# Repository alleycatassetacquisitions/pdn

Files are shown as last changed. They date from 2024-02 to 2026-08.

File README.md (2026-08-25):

# Portable Data Node (PDN) by Alleycat Asset Acquisitions

Welcome to the official repository for Alleycat Asset Acquisitions' **Portable Data Node (PDN)** project. The PDN is a cutting-edge, interactive device used in live-action role-playing (LARP) environments like [Neotropolis](https://www.neotropolis.com). It leverages real-time technology and augmented reality to create immersive gameplay experiences. The PDN serves as a versatile tool for communication, mission tracking, and player interaction.

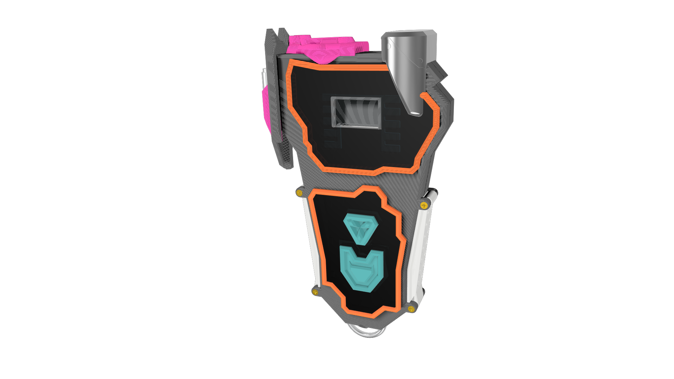
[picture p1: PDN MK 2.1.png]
PDN MK 2.1 Fusion Model (https://a360.co/4ls4MnI)

Clicking on the image will take you to the fusion 360 project!

PCB's were designed in KiCad 8 and will be uploaded to a separate repository soon.

## Table of Contents

- [About the Project](#about-the-project)
- [Project Goals](#project-goals)
- [Features](#features)
- [Installation](#installation)
- [Usage](#usage)
- [Development](#development)
- [Contributing](#contributing)
- [License](#license)
- [Contact](#contact)

## About the Project

The Alleycat Asset Acquisitions Portable Data Node is the premiere device for facilitating immersive experiences and in person, interactive play. You can find Elli Furedy's talk from Hackaday Supercon 2025 on the PDN and Alleycat's philosophies [here](https://youtu.be/ndodsA254HA).

You can find the developer wiki [here](https://deepwiki.com/alleycatassetacquisitions/pdn).

## Project Goals

- **Immersive Icebreaker**: At it's core, the PDN is designed to facilitate face to face experiences.
- **Open Source Collaboration**: Foster collaboration by making the PDN's software and hardware designs available to the community for further improvement. Check out the PDN CLI tool for development tools without needing a physical device.

## Features

- **Extensible Platform**: The PDN currently supports a single experience - the Neotropolis Quickdraw game, however, it is trivial to create new State Machines to support new game experiences.
- **Peripheral Rich**: The base PDN design supports a 128x64 OLED, 19 LEDs, vibration haptics, 2 buttons, ESP-NOW, HTTP and Serial communication.
- **Real-Time Tracking**: The PDN supports connecting to a server to update player data in real time.
- **Modular Design**: The PDN framework works off of a "Driver" framework that allows for customizing the hardware, whether to support new hardware platforms or new peripherals.

## Installation

### Prerequisites

- **PlatformIO Core**: Ensure you have PlatformIO installed as it is used for development and flashing the firmware.
- **pioarduino Platform**: This project uses [pioarduino](https://github.com/pioarduino/platform-espressif32), a community fork of the Espressif32 platform with support for newer ESP-IDF and Arduino framework versions.
- **Unix Style Terminal**: Required for the CLI simulator tool. Windows users should use WSL (Windows Subsystem for Linux).

### Steps

1. Clone the repository:
   ```bash
   git clone https://github.com/AlleycatAssetAcquisitions/pdn
   ```

2. Navigate to the project directory:
   ```bash
   cd pdn/
   ```

3. Install PlatformIO Core:
   ```bash
   pip install platformio
   # or
   platformio upgrade
   ```

4. Configure WiFi credentials (for ESP32-S3 builds):
   ```bash
   cp wifi_credentials.ini.example wifi_credentials.ini
   ```
   Then edit `wifi_credentials.ini` with your WiFi SSID, password, and API base URL. This file is excluded from version control for security.

5. Build the project using PlatformIO:
   ```bash
   pio run -e <build-target>
   ```
   Depending on your use case, there are a number of build targets:
   - `esp32-s3_pdn_release` - Release build (NO LOGS)
   - `esp32-s3_pdn_debug` - Standard Development build
   - `native_cli` - Build the native CLI tool for simulated development (Unix/WSL only)

6. Flash the PDN firmware to your device:
   ```bash
   platformio run --target upload
   ```

### Migration from Standard PlatformIO Espressif32

This project recently migrated from the standard PlatformIO Espressif32 platform to **pioarduino** for access to newer ESP-IDF versions and improved Arduino framework support.

Uninstall PlatformIO from your IDE.
Install pioarduino.
Restart your IDE.

If you're experiencing build issues after pulling recent changes, perform a clean install:

```bash
# Remove old platform packages
rm -rf ~/.platformio/platforms/espressif32*
rm -rf ~/.platformio/packages/framework-arduinoespressif32*

# Clean the project build cache
rm -rf .pio/

# Rebuild
pio run -e esp32-s3_pdn_release
```

## Usage

1. **Power on the PDN**: Once powered, the PDN will ask for your player registration code. This is a 4 digit code that is transmitted to the server to fetch player details. The **top button** cycles through digits, 0 through 9, while the **bottom button** functions as a confirm operation.

2. **Log in to Device**: After entering the code, the device will attempt to fetch data from the server. If there is no server running, it will default to offline mode. You will need to **confirm the player code**, **select a role - Hunter/Bounty** and then confirm. The device will launch into the idle state and you will then be able to practice quickdraw duels with another device.

3. **For Simulated Development**: See CLI_README.md for development without a hardware device.

## Development

### Local Development

If you want to contribute to the PDN Project, follow these steps to set up your local development environment:

1. **Fork the repository** and create your development branch:
   ```bash
   git checkout -b feature/NewFeature
   ```

2. **Develop your feature**
3. **Test on Device/CLI** - CLI tests are sufficient if the hardware layer is unchanged, if any changes are made to drivers our core device logic, features need to be tested on device as well.
3. **Add any new tests** - these should be located in `test/test_core` or `test/test_cli`
4. **Run the test suite** - ensure your changes haven't broken any unit tests.
   ```bash
   pio test -e native          # Core unit tests
   pio test -e native_cli_test # CLI-specific tests
   ```
   CI also gates on the core suite under sanitizers. Run those binaries directly:
   a default `pio test` prints only lines its googletest parser recognizes, so a
   sanitizer report is dropped.
   ```bash
   pio test -e native_asan --without-testing && ./.pio/build/native_asan/program
   pio test -e native_tsan --without-testing && ./.pio/build/native_tsan/program
   ```
5. **Commit and push your changes**:
   ```bash
   git commit -m "Add New Feature"
   git push origin feature/NewFeature
   ```
6. **Create a pull request** for review. Ensure your PR is passing all checks before merging.

### Code Structure

- `include/device/`: This is the hardware abstraction layer that hides all the hardware implementation.
- `include/device/drivers/`: Provides the concrete implementation of hardware peripherals. The native drivers are used for running the CLI tool. 
- `include/game/`: Contains code for game experiences.
- `include/state/`: The core plumbing of the State Machine, the core class that powers games.
- `test/`: Unit testing files for ensuring code stability.
- `platformio.ini`: Project configuration file for PlatformIO, defining build environments and dependencies.

## Contributing

Alleycat wants YOUR HELP! Whether you have feature suggestions, bug reports, or improvements, please follow our [contributing guidelines](CONTRIBUTING.md).

### How to Contribute

1. **Fork the repository**.
2. **Create a new branch** for your feature or bug fix.
3. **Commit your changes** with a descriptive message.
4. **Submit a pull request** for review.

## License

This project is licensed under the MIT License. See the [LICENSE](LICENSE) file for details.

## Contact

For any questions, collaboration opportunities, or technical issues, please reach out to us:

- **Email**: [alleycatassetacquisitions@gmail.com](mailto:alleycatassetacquisitions@gmail.com)
- **Website**: [alleycat.agency](https://alleycat.agency)

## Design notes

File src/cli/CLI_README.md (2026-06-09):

# PDN CLI Simulator

The CLI tool allows you to simulate a network of pdn's to test and build games without having to worry about device deployment and hw related concerns

## Platform Requirements

**Unix/POSIX only** Windows users should use WSL or Git Bash.

The tool requires POSIX terminal APIs (`termios`, `fcntl`) for raw input handling and ANSI escape codes for the UI.

## Building

```bash
pio run -e native_cli
```

## Running

```bash
.pio/build/native_cli/program [num_devices]
```

- `num_devices` (optional): Number of PDN devices to spawn (default: 2)
- Devices alternate roles: Device 0 = Hunter, Device 1 = Bounty, Device 2 = Hunter, etc.
- Device IDs start at `0010` and increment

## Controls

| Key | Action |
|-----|---|
| `←` / `→` | Select previous/next device |
| `↑` | Primary button press (selected device) |
| `↓` | Secondary button press (selected device) |
| `q` | Quit simulator |

## Commands

Type commands at the prompt and press Enter:

| Command | Description |
|---|---|
| `help` | Show all available commands |
| `select <n>` | Select device by index (e.g., `select 1`) |
| `add [hunter\|bounty]` | Add a new device at runtime |
| `cable <a> <b>` | Connect devices via serial cable |
| `disconnect <n>` | Disconnect device's serial cable |
| `press <n> [primary\|secondary]` | Simulate button press |
| `longpress <n> <ms>` | Simulate long press with duration |
| `peer <src> <dst> <type> [hex]` | Send ESP-NOW packet between devices |
| `inject <dst> <type> [hex]` | Inject ESP-NOW packet from external source |
| `state` | Show all device states |
| `http [online\|offline]` | Toggle mock HTTP server state |

## UI Panel

The selected device displays a detailed panel showing:

- **Player Info**: ID, allegiance, win/loss record
- **State**: Current game state with history
- **Display**: Simulated 128x64 OLED content (text mode)
- **LEDs**: Left/Right light strips with RGB values
- **Serial Ports**: Buffer sizes, connection status, TX/RX history
- **ESP-NOW**: Connection state, MAC address, packet history
- **HTTP**: Mock server status, request history
- **Errors**: Recent LOG_E messages

## Serial Cable Simulation

The `cable` command simulates plugging in an audio cable between two devices:

- **Hunter ↔ Bounty**: Connects Primary-to-Primary jacks (normal gameplay)
- **Same role**: Connects Primary-to-Auxiliary jacks

Example workflow:
```
cable 0 1          # Connect hunter (0) to bounty (1)
disconnect 0       # Disconnect device 0's cable
```

## Mock HTTP Server

The simulator includes a mock HTTP server that handles:

- `GET /api/players/{id}` - Returns player data
- `PUT /api/matches` - Accepts match uploads

Use `http offline` to simulate network failures.

## Example Session

```bash
# Start with 2 devices (hunter + bounty)
.pio/build/native_cli/program 2

# In the simulator:
cable 0 1              # Connect devices - starts handshake
# Watch devices progress through: Idle → Handshake → ConnectionSuccessful → DuelCountdown → Duel

# Press buttons during duel
press 0 primary        # Hunter presses button
press 1 primary        # Bounty presses button
```

## Architecture

The CLI simulator reuses the core PDN game logic with native driver implementations:

- `NativeSerialDriver` - Buffered serial with cable broker integration
- `NativePeerCommsDriver` - ESP-NOW simulation via `NativePeerBroker`
- `NativeHttpClientDriver` - Mock HTTP via `MockHttpServer`
- `NativeDisplayDriver` - Text-based display capture
- `NativeLightStripDriver` - LED state tracking
- `NativeButtonDriver` - Callback-based button simulation

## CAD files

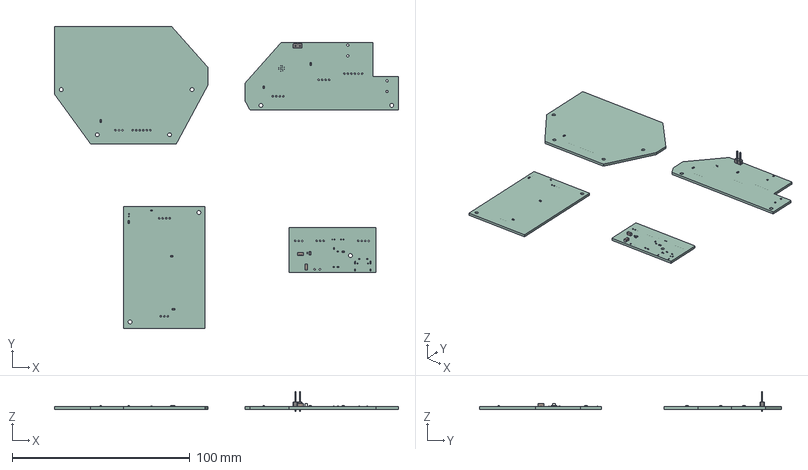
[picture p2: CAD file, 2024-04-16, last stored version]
pdn-pcb/PDN.step
193.7 x 169.8 x 11.5 mm
PCB1
PCB2
PCB3
PCB4

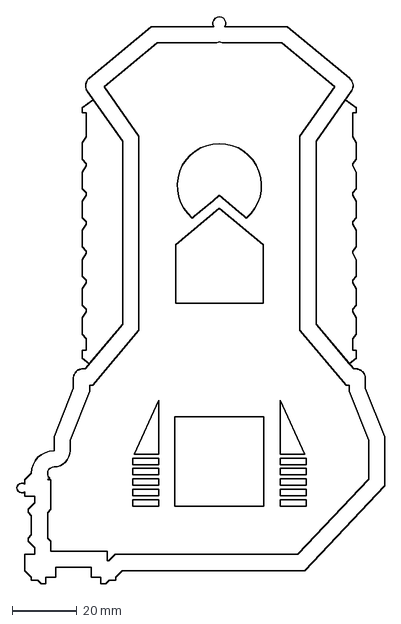
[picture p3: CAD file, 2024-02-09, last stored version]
pdn-pcb/outline.dxf
113.7 x 175.0 mm

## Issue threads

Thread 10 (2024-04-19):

flip the audio jack from "flipped arrangement of ground first" to avoid shorts

FinallyEve, 2024-04-19:

Closed 2024-07-03.

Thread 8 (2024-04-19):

add a rule that if you press during countdown, you lose to avoid holding down button

FinallyEve, 2024-04-19:
reminder

Closed 2024-07-03.

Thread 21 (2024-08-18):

Target Selection Design Doc

FinallyEve, 2024-08-18:
Need to render a list of who is nearby:
- tie a device ping to an identity (currently done, player info bcast in Dan's branch [name, role, id])
- need to display to user the list of nearby (sorted by LIFO order) aka most recent pings
- Some means of cycling through list of nearby users
- Selecting a user will cause that user's PDN to react through lighting up
- Attacking user then confirms selection and initiates targeting.

Possible Powerup Interactions:
- Stealth (doesn't alert user)
- Cloaking - User doesn't show up in other player's pings.

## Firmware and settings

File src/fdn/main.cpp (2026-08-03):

#include <Arduino.h>

#include <WiFi.h>
#include <FastLED.h>
#include <Preferences.h>

#include "device/crash/crash-logger.hpp"
#include "device/drivers/esp32-s3/esp32-s3-logger-driver.hpp"
#include "device/drivers/esp32-s3/esp32-s3-clock-driver.hpp"
#include "device/drivers/esp32-s3/esp32-s3-1-button-driver.hpp"
#include "device/drivers/esp32-s3/ws2812b-fastled-driver.hpp"
#include "device/drivers/esp32-s3/esp32-s3-haptics-driver.hpp"
#include "device/drivers/esp32-s3/esp32-s3-serial-driver.hpp"
#include "device/drivers/esp32-s3/esp32-s3-http-client-driver.hpp"
#include "device/drivers/esp32-s3/esp-now-driver.hpp"
#include "device/drivers/esp32-s3/ssd1309-u8g2-driver.hpp"
#include "device/drivers/esp32-s3/esp32-s3-prefs-driver.hpp"

#include "fdn-constants.hpp"
#include "utils/simple-timer.hpp"
#include "game/player.hpp"
#include "device/fdn.hpp"
#include "wireless/remote-player-manager.hpp"
#include "wireless/fdn-connect-wireless-manager.hpp"
#include "wireless/symbol-wireless-manager.hpp"
#include "wireless/wireless-types.hpp"
#include "device/drivers/peer-comms-interface.hpp"
#include "apps/main-menu/main-menu.hpp"
#include "apps/idle/idle.hpp"
#include "apps/hacking/hacking.hpp"
#include "apps/hacking/hacked-players-manager.hpp"
#include "apps/symbol-match/symbol-match.hpp"
#include "apps/fdn-app-ids.hpp"

// WiFi configuration - injected at compile time from wifi_credentials.ini
// See wifi_credentials.ini.example for template
#ifndef WIFI_SSID
#error "WIFI_SSID not defined. Please create wifi_credentials.ini from wifi_credentials.ini.example"
#endif
#ifndef WIFI_PASSWORD
#error "WIFI_PASSWORD not defined. Please create wifi_credentials.ini from wifi_credentials.ini.example"
#endif
#ifndef BASE_URL
#error "BASE_URL not defined. Please create wifi_credentials.ini from wifi_credentials.ini.example"
#endif

WifiConfig* wifiConfig = nullptr;
CrashLogger* crashLogger = nullptr;
// ESP32-S3 Drivers
Esp32S3Clock*    clockDriver              = nullptr;
SSD1309U8G2Driver* displayDriver         = nullptr;
Esp32S31ButtonDriver* primaryButtonDriver   = nullptr;
Esp32S31ButtonDriver* secondaryButtonDriver = nullptr;
Esp32S31ButtonDriver* tertiaryButtonDriver  = nullptr;
// Recess lights on DISPLAY pin slot, fin lights on GRIP pin slot
WS2812BFastLEDDriver<fdnRecessLightsPin, fdnFinLightsPin>* lightDriver = nullptr;
Esp32S3HapticsDriver* hapticsDriver      = nullptr;
Esp32s3SerialIn* serialInDriver          = nullptr;
Esp32s3SerialInSecondary* serialInSecondaryDriver = nullptr;
Esp32S3HttpClient* httpClientDriver      = nullptr;
EspNowDriver*   peerCommsDriver         = nullptr;
Esp32S3Logger*   loggerDriver            = nullptr;
Esp32S3PrefsDriver* storageDriver        = nullptr;

// FDN device
FDN* fdn = nullptr;

// Player identity
Player fdnPlayer = FDN_PLAYER;

// Managers
RemotePlayerManager*      remotePlayerManager      = nullptr;
FDNConnectWirelessManager* fdnConnectWirelessManager = nullptr;
HackedPlayersManager*     hackedPlayersManager     = nullptr;
SymbolWirelessManager*    symbolWirelessManager    = nullptr;

// Apps
MainMenu*    mainMenu        = nullptr;
Idle*        idleApp         = nullptr;
Hacking*     hackingApp      = nullptr;
SymbolMatch* symbolMatchApp  = nullptr;

static constexpr unsigned long PLAYER_BROADCAST_INTERVAL_MS = 12000;

static void setupEspNow(PeerCommsInterface* peerComms) {
    peerComms->setPacketHandler(
        PktType::kPlayerInfoBroadcast,
        [](const uint8_t* src, const uint8_t* data, size_t len, void* arg) {
            static_cast<RemotePlayerManager*>(arg)->ProcessPlayerInfoPkt(src, data, len);
        },
        remotePlayerManager);

    peerComms->setPacketHandler(
        PktType::kFdnConnect,
        [](const uint8_t* src, const uint8_t* data, size_t len, void* arg) {
            static_cast<FDNConnectWirelessManager*>(arg)->processPacket(src, data, len);
        },
        fdnConnectWirelessManager);

    peerComms->setPacketHandler(
        PktType::kSymbolMatchCommand,
        [](const uint8_t* src, const uint8_t* data, size_t len, void* arg) {
            static_cast<SymbolWirelessManager*>(arg)->processSymbolMatchCommand(src, data, len);
        },
        symbolWirelessManager);
}

void setup() {
    Serial.begin(115200);
    // Do not block on Serial — USB CDC may have no host in the field; setup must run anyway.

    // Construct platform drivers first — logging and timers depend on these.
    loggerDriver = new Esp32S3Logger(LOGGER_DRIVER_NAME);
    clockDriver  = new Esp32S3Clock(PLATFORM_CLOCK_DRIVER_NAME);

    g_logger = loggerDriver;
    SimpleTimer::setPlatformClock(clockDriver);
    esp_log_level_set("*", ESP_LOG_VERBOSE);

    // Remaining drivers (safe to log now)
    displayDriver = new SSD1309U8G2Driver(
        DISPLAY_DRIVER_NAME, fdnDisplayCS, fdnDisplayDC, fdnDisplayRST);
    primaryButtonDriver   = new Esp32S31ButtonDriver(PRIMARY_BUTTON_DRIVER_NAME,   fdnPrimaryButtonPin);
    secondaryButtonDriver = new Esp32S31ButtonDriver(SECONDARY_BUTTON_DRIVER_NAME, fdnSecondaryButtonPin);
    tertiaryButtonDriver  = new Esp32S31ButtonDriver(TERTIARY_BUTTON_DRIVER_NAME,  fdnTertiaryButtonPin);
    lightDriver = new WS2812BFastLEDDriver<fdnRecessLightsPin, fdnFinLightsPin>(
        LIGHT_DRIVER_NAME, fdnNumRecessLights, fdnNumFinLights);
    hapticsDriver = new Esp32S3HapticsDriver(HAPTICS_DRIVER_NAME, fdnMotorPin);
    serialInDriver          = new Esp32s3SerialIn(SERIAL_IN_DRIVER_NAME, fdnRXt, fdnRXr);
    serialInSecondaryDriver = new Esp32s3SerialInSecondary(SERIAL_IN_SECONDARY_DRIVER_NAME, fdnRXt2, fdnRXr2);

    wifiConfig    = new WifiConfig(WIFI_SSID, WIFI_PASSWORD, BASE_URL);
    peerCommsDriver = EspNowDriver::CreateEspNowManager(PEER_COMMS_DRIVER_NAME);
    httpClientDriver = new Esp32S3HttpClient(HTTP_CLIENT_DRIVER_NAME, wifiConfig);
    storageDriver = new Esp32S3PrefsDriver(STORAGE_DRIVER_NAME, {FDN_PREF_NAMESPACE, CRASH_LOG_NAMESPACE});

    DriverConfig fdnConfig = {
        {DISPLAY_DRIVER_NAME,              displayDriver},
        {PRIMARY_BUTTON_DRIVER_NAME,       primaryButtonDriver},
        {SECONDARY_BUTTON_DRIVER_NAME,     secondaryButtonDriver},
        {TERTIARY_BUTTON_DRIVER_NAME,      tertiaryButtonDriver},
        {LIGHT_DRIVER_NAME,                lightDriver},
        {HAPTICS_DRIVER_NAME,              hapticsDriver},
        {SERIAL_IN_DRIVER_NAME,            serialInDriver},
        {SERIAL_IN_SECONDARY_DRIVER_NAME,  serialInSecondaryDriver},
        {HTTP_CLIENT_DRIVER_NAME,          httpClientDriver},
        {PEER_COMMS_DRIVER_NAME,           peerCommsDriver},
        {PLATFORM_CLOCK_DRIVER_NAME,       clockDriver},
        {LOGGER_DRIVER_NAME,               loggerDriver},
        {STORAGE_DRIVER_NAME,              storageDriver},
    };

    fdn = FDN::createFDN(fdnConfig);
    fdn->begin();

    // Managers — constructed after fdn->begin() so wireless is ready.
    remotePlayerManager = new RemotePlayerManager(peerCommsDriver);
    remotePlayerManager->StartBroadcastingPlayerInfo(&fdnPlayer, PLAYER_BROADCAST_INTERVAL_MS);

    fdnConnectWirelessManager = new FDNConnectWirelessManager();
    fdnConnectWirelessManager->initialize(fdn->getWirelessManager());

    hackedPlayersManager  = new HackedPlayersManager(fdn->getStorage());

    symbolWirelessManager = new SymbolWirelessManager();
    symbolWirelessManager->initialize(fdn->getWirelessManager(), fdn->getRemoteDeviceCoordinator());

    setupEspNow(peerCommsDriver);

    crashLogger = new CrashLogger(storageDriver, peerCommsDriver);
    crashLogger->capture();
    crashLogger->transmitPending();

    // Apps
    idleApp = new Idle(
        remotePlayerManager, hackedPlayersManager,
        fdnConnectWirelessManager, fdn->getRemoteDeviceCoordinator());

    mainMenu = new MainMenu(fdn, remotePlayerManager);

    hackingApp = new Hacking(
        fdnConnectWirelessManager, hackedPlayersManager,
        fdn->getRemoteDeviceCoordinator());

    symbolMatchApp = new SymbolMatch(
        fdn, symbolWirelessManager,
        remotePlayerManager, hackedPlayersManager,
        fdnConnectWirelessManager);

    // Splash screen
    fdn->getDisplay()
        ->invalidateScreen()
        ->drawText("ALLEYCAT", 20, 32)
        ->render();
    delay(2000);

    AppConfig apps = {
        {StateId(SYMBOL_MATCH_APP_ID), symbolMatchApp},
        {StateId(MAIN_MENU_APP_ID),    mainMenu},
        {StateId(HACKING_APP_ID),      hackingApp},
        {StateId(IDLE_APP_ID),         idleApp},
    };
    fdn->loadAppConfig(apps, StateId(SYMBOL_MATCH_APP_ID));
}

void loop() {
    if (crashLogger != nullptr) {
        crashLogger->pollSerialCommand();
    }
    fdn->loop();
}

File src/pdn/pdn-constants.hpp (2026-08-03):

#pragma once

#include <cstdint>

// --- GPIO pin assignments ---
constexpr uint8_t primaryButtonPin   = 15;
constexpr uint8_t secondaryButtonPin = 16;
constexpr uint8_t motorPin           = 17;
constexpr uint8_t RXr                = 41;
constexpr uint8_t RXt                = 40;
constexpr uint8_t TXt                = 39; // MIDDLE BAND ON AUDIO CABLE
constexpr uint8_t TXr                = 38; // TIP OF AUDIO CABLE
constexpr uint8_t displayLightsPin   = 13;
constexpr uint8_t gripLightsPin      = 21;
constexpr uint8_t displayCS          = 10;
constexpr uint8_t displayDC          = 9;
constexpr uint8_t displayRST         = 14;

// --- LED strip lengths ---
constexpr uint8_t numDisplayLights = 13;
constexpr uint8_t numGripLights    = 6;

// --- Game timing ---
constexpr unsigned long DUEL_NO_RESULT_TIME = 123456789;

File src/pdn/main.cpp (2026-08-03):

#include <Arduino.h>

#include <WiFi.h>
#include <FastLED.h>
#include <Preferences.h>

#include "device/drivers/esp32-s3/esp32-s3-logger-driver.hpp"
#include "device/drivers/esp32-s3/esp32-s3-clock-driver.hpp"
#include "device/drivers/esp32-s3/esp32-s3-1-button-driver.hpp"
#include "device/drivers/esp32-s3/ws2812b-fastled-driver.hpp"
#include "device/drivers/esp32-s3/esp32-s3-haptics-driver.hpp"
#include "device/drivers/esp32-s3/esp32-s3-serial-driver.hpp"
#include "device/drivers/esp32-s3/esp32-s3-http-client-driver.hpp"
#include "device/drivers/esp32-s3/esp-now-driver.hpp"
#include "device/drivers/esp32-s3/ssd1306-u8g2-driver.hpp"
#include "device/drivers/esp32-s3/esp32-s3-prefs-driver.hpp"
#include "device/crash/crash-logger.hpp"

#include "pdn-constants.hpp"
#include "utils/simple-timer.hpp"
#include "game/player.hpp"
#include "state/state-machine.hpp"
#include "device/pdn.hpp"
#include "game/quickdraw.hpp"
#include "id-generator.hpp"
#include "wireless/remote-player-manager.hpp"
#include "game/match-manager.hpp"
#include "wireless/wireless-types.hpp"
#include "wireless/quickdraw-wireless-manager.hpp"
#include "wireless/remote-debug-manager.hpp"
#include "wireless/symbol-wireless-manager.hpp"
#include "device/drivers/peer-comms-interface.hpp"
#include "game/quickdraw-resources.hpp"

// WiFi configuration - injected at compile time from wifi_credentials.ini
// See wifi_credentials.ini.example for template
#ifndef WIFI_SSID
#error "WIFI_SSID not defined. Please create wifi_credentials.ini from wifi_credentials.ini.example"
#endif
#ifndef WIFI_PASSWORD
#error "WIFI_PASSWORD not defined. Please create wifi_credentials.ini from wifi_credentials.ini.example"
#endif
#ifndef BASE_URL
#error "BASE_URL not defined. Please create wifi_credentials.ini from wifi_credentials.ini.example"
#endif

WifiConfig* wifiConfig = nullptr;

CrashLogger* crashLogger = nullptr;


// ESP32-s3 Drivers (declare as pointers, construct in setup())
Esp32S3Clock* clockDriver = nullptr;
SSD1306U8G2Driver* displayDriver = nullptr;
Esp32S31ButtonDriver* primaryButtonDriver = nullptr;
Esp32S31ButtonDriver* secondaryButtonDriver = nullptr;
WS2812BFastLEDDriver<displayLightsPin, gripLightsPin>* lightDriver = nullptr;
Esp32S3HapticsDriver* hapticsDriver = nullptr;
Esp32s3SerialOut* serialOutDriver = nullptr;
Esp32s3SerialIn* serialInDriver = nullptr;
Esp32S3HttpClient* httpClientDriver = nullptr;
EspNowDriver* peerCommsDriver = nullptr;
Esp32S3Logger* loggerDriver = nullptr;
Esp32S3PrefsDriver* storageDriver = nullptr;

// Core game objects (declare as pointers, construct in setup())
Device* pdn = nullptr;
Player* player = nullptr;

// Game instance
Quickdraw* game = nullptr;

// Remote player management
QuickdrawWirelessManager* quickdrawWirelessManager = nullptr;
SymbolWirelessManager* symbolWirelessManager = nullptr;
RemoteDebugManager* remoteDebugManager = nullptr;

void setupEspNow(
    QuickdrawWirelessManager* quickdrawWirelessManager,
    RemoteDebugManager* remoteDebugManager,
    SymbolWirelessManager* symbolWirelessManager,
    PeerCommsInterface* peerCommsDriver) {
    // Register packet handlers
    peerCommsDriver->setPacketHandler(
        PktType::kQuickdrawCommand,
        [](const uint8_t* src, const uint8_t* data, const size_t len, void* userArg) {
            ((QuickdrawWirelessManager*)userArg)->processQuickdrawCommand(src, data, len);
        },
        quickdrawWirelessManager
    );
    
    peerCommsDriver->setPacketHandler(
        PktType::kDebugPacket,
        [](const uint8_t* srcAddr, const uint8_t* data, const size_t len, void* userArg) {
            ((RemoteDebugManager*)userArg)->ProcessDebugPacket(srcAddr, data, len);
        },
        remoteDebugManager
    );

    peerCommsDriver->setPacketHandler(
        PktType::kSymbolMatchCommand,
        [](const uint8_t* srcAddr, const uint8_t* data, const size_t len, void* userArg) {
            ((SymbolWirelessManager*)userArg)->processSymbolMatchCommand(srcAddr, data, len);
        },
        symbolWirelessManager
    );
}

void setup() {
    Serial.begin(115200);
    // Do not block on Serial — USB CDC may have no host in the field; setup must run anyway.

    // Construct drivers FIRST (before anything that might use logging or timers)
    loggerDriver = new Esp32S3Logger(LOGGER_DRIVER_NAME);
    clockDriver = new Esp32S3Clock(PLATFORM_CLOCK_DRIVER_NAME);
    
    // Initialize platform abstractions immediately after constructing them
    g_logger = loggerDriver;
    SimpleTimer::setPlatformClock(clockDriver);
    esp_log_level_set("*", ESP_LOG_VERBOSE);

    // Now construct remaining drivers (safe to use logging and timers now)
    displayDriver = new SSD1306U8G2Driver(DISPLAY_DRIVER_NAME, displayCS, displayDC, displayRST);
    primaryButtonDriver = new Esp32S31ButtonDriver(PRIMARY_BUTTON_DRIVER_NAME, primaryButtonPin);
    secondaryButtonDriver = new Esp32S31ButtonDriver(SECONDARY_BUTTON_DRIVER_NAME, secondaryButtonPin);
    lightDriver = new WS2812BFastLEDDriver<displayLightsPin, gripLightsPin>(LIGHT_DRIVER_NAME, numDisplayLights, numGripLights);
    hapticsDriver = new Esp32S3HapticsDriver(HAPTICS_DRIVER_NAME, motorPin);
    serialOutDriver = new Esp32s3SerialOut(SERIAL_OUT_DRIVER_NAME, TXt, TXr);
    serialInDriver = new Esp32s3SerialIn(SERIAL_IN_DRIVER_NAME, RXt, RXr);
    
    // WiFi credentials are compile-time constants from build flags
    wifiConfig = new WifiConfig(WIFI_SSID, WIFI_PASSWORD, BASE_URL);
    peerCommsDriver = EspNowDriver::CreateEspNowManager(PEER_COMMS_DRIVER_NAME);
    httpClientDriver = new Esp32S3HttpClient(HTTP_CLIENT_DRIVER_NAME, wifiConfig);
    storageDriver = new Esp32S3PrefsDriver(STORAGE_DRIVER_NAME, {MATCHES_PREFS_NAMESPACE, CRASH_LOG_NAMESPACE});

    // Create driver configuration
    DriverConfig pdnConfig = {
        {DISPLAY_DRIVER_NAME, displayDriver},
        {PRIMARY_BUTTON_DRIVER_NAME, primaryButtonDriver},
        {SECONDARY_BUTTON_DRIVER_NAME, secondaryButtonDriver},
        {LIGHT_DRIVER_NAME, lightDriver},
        {HAPTICS_DRIVER_NAME, hapticsDriver},
        {SERIAL_OUT_DRIVER_NAME, serialOutDriver},
        {SERIAL_IN_DRIVER_NAME, serialInDriver},
        {HTTP_CLIENT_DRIVER_NAME, httpClientDriver},
        {PEER_COMMS_DRIVER_NAME, peerCommsDriver},
        {PLATFORM_CLOCK_DRIVER_NAME, clockDriver},
        {LOGGER_DRIVER_NAME, loggerDriver},
        {STORAGE_DRIVER_NAME, storageDriver},
    };
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

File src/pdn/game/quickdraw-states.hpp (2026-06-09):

#pragma once

#include "device/pdn.hpp"
#include "game/player.hpp"
#include "utils/simple-timer.hpp"
#include "utils/debounced-condition.hpp"
#include "state/state.hpp"
#include "state/connect-state.hpp"
#include "wireless/quickdraw-wireless-manager.hpp"
#include "wireless/symbol-wireless-manager.hpp"
#include "wireless/remote-debug-manager.hpp"
#include "game/match-manager.hpp"
#include "device/drivers/http-client-interface.hpp"
#include "game/quickdraw-resources.hpp"
#include <array>
#include <atomic>
#include <cstddef>
#include <cstdlib>
#include <queue>
#include <string>
#include "device/remote-device-coordinator.hpp"
#include "game/chain-duel-manager.hpp"
#include "game/shootout-manager.hpp"

enum QuickdrawStateId {
    SLEEP = 6,
    AWAKEN_SEQUENCE = 7,
    IDLE = 8,
    DUEL_COUNTDOWN = 13,
    DUEL = 14,
    DUEL_PUSHED = 15,
    DUEL_RECEIVED_RESULT = 16,
    DUEL_RESULT = 17,
    WIN = 18,
    LOSE = 19,
    UPLOAD_MATCHES = 20,
    SUPPORTER_READY = 21,
    SHOOTOUT_PROPOSAL = 22,
    SHOOTOUT_BRACKET_REVEAL = 23,
    SHOOTOUT_SPECTATOR = 24,
    SHOOTOUT_ELIMINATED = 25,
    SHOOTOUT_FINAL_STANDINGS = 26,
    SHOOTOUT_ABORTED = 27,
    // Symbol-match IDs sit after the shootout block so neither protocol's
    // wire-visible state IDs collide. Main introduced SYMBOL=22/SYMBOL_MATCHED=23
    // in parallel with shootout taking 22-27; they were renumbered here on merge.
    SYMBOL = 28,
    SYMBOL_MATCHED = 29,
};

class Sleep : public TypedState<PDN> {
public:
    explicit Sleep(Player* player);
    ~Sleep();

    void onStateMounted(PDN* pdn) override;
    void onStateLoop(PDN* pdn) override;
    void onStateDismounted(PDN* pdn) override;
    bool transitionToAwakenSequence();

private:
    bool transitionToAwakenSequenceState = false;
    SimpleTimer dormantTimer;
    Player* player;
    bool breatheUp = true;
    int ledBrightness = 0;
    float pwm_val = 0.0;
    static constexpr int smoothingPoints = 255;
    static constexpr unsigned long SLEEP_DURATION = 60000UL;
};

class AwakenSequence : public TypedState<PDN> {
public:
    explicit AwakenSequence(Player* player);
    ~AwakenSequence();
    void onStateMounted(PDN* pdn) override;
    void onStateLoop(PDN* pdn) override;
    void onStateDismounted(PDN* pdn) override;
    bool transitionToIdle();

private:
    static constexpr int AWAKEN_THRESHOLD = 20;
    SimpleTimer activationSequenceTimer;
    int activateMotorCount = 0;
    bool activateMotor = false;
    const int activationStepDuration = 100;
    Player* player;
};

class Idle : public ConnectState<PDN> {
public:
    Idle(Player *player, MatchManager* matchManager, RemoteDeviceCoordinator* remoteDeviceCoordinator, ChainDuelManager* chainDuelManager);
    ~Idle();

    void onStateMounted(PDN* pdn) override;
    void onStateLoop(PDN* pdn) override;
    void onStateDismounted(PDN* pdn) override;
    bool transitionToDuelCountdown();
    bool transitionToSupporterReady();
    void renderStats(PDN* pdn);
    bool transitionToSymbol();

private:
    Player *player;
    MatchManager* matchManager;
    ChainDuelManager* chainDuelManager;
    bool matchInitialized = false;
    bool displayIsDirty = false;
    int statsIndex = 0;
    int statsCount = 7;
    size_t lastPosseCount = 0;

    bool isPrimaryRequired() override;
    bool isAuxRequired() override;

    SimpleTimer matchInitializationTimer;
    const int MATCH_INITIALIZATION_TIMEOUT = 1000;

    bool transitionToSymbolState = false;

    // void serialEventCallbacks(const std::string& message);
};

class SupporterReady : public ConnectState<PDN> {
public:
    SupporterReady(Player *player, RemoteDeviceCoordinator* remoteDeviceCoordinator, ChainDuelManager* chainDuelManager);
    ~SupporterReady();

    void onStateMounted(PDN* pdn) override;
    void onStateLoop(PDN* pdn) override;
    void onStateDismounted(PDN* pdn) override;
    bool transitionToIdle();

    // Called by Quickdraw's chain-game-event packet handler.
    void onChainGameEventReceived(uint8_t event_type, const uint8_t* senderMac);

public:
    // Button callback in onStateMounted uses these via `this` capture.
    // Atomic because the ESP-NOW packet callback (WiFi task on hardware) and
    // the button press / state-loop callbacks (main task) read and write them
    // concurrently.
    Player *player;
    std::atomic<bool> buttonArmed{false};
    std::atomic<bool> hasConfirmed{false};
    std::atomic<bool> displayIsDirty{true};
    std::atomic<bool> ledsAreDirty{true};
    std::atomic<int> lastResult{0};
    // resultClearTimer is touched only by onStateLoop (main task). The
    // packet handler (WiFi task) communicates via the atomic lastResult;
    // onStateLoop detects transitions and manages the timer here.
    SimpleTimer resultClearTimer;
    PDN* cachedPDN = nullptr;

    void startLEDs(PDN* pdn, bool armed, bool confirmed);

private:
    ChainDuelManager* chainDuelManager;
    bool transitionToIdleFlag = false;
    int lastProcessedResult_ = 0;  // main-task-only; mirrors lastResult

    bool isPrimaryRequired() override;
    bool isAuxRequired() override;
};



class DuelCountdown : public ConnectState<PDN> {
public:
    DuelCountdown(Player* player, MatchManager* matchManager, RemoteDeviceCoordinator* remoteDeviceCoordinator, ChainDuelManager* chainDuelManager);
    ~DuelCountdown();

    void onStateMounted(PDN* pdn) override;
    void onStateLoop(PDN* pdn) override;
    void onStateDismounted(PDN* pdn) override;
    bool shallWeBattle();
    bool disconnectedBackToIdle();

    bool isPrimaryRequired() override;
    bool isAuxRequired() override;
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

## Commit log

2023-10-22 Initial Commit of KiCad Project.
    [PDN.kicad_pcb, PDN.kicad_sch]
2023-10-25 More Parts from JLCPCB
    [PDN.kicad_sch]
2024-02-09 V1 PCB Dev Boards.
    [PDN.kicad_pcb, PDN.kicad_sch, PDN.step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]
2024-03-04 Updated 3v3 LDO to an LDL1117, reworked the brain board and added TVS protection.
    [PDN.kicad_pcb, PDN.kicad_sch, PDN.step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]
2024-03-04 Updated display, user board and display board.
    [PDN.kicad_pcb, brain.kicad_sch, display.kicad_sch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]
2024-03-15 Connected D1 & D2 of Display.
    [PDN.kicad_pcb]
2024-03-15 Fix DRC violations, update side leds.
    [PDN.kicad_pcb]
2024-03-16 Update Brain Board.
    [PDN.kicad_pcb, brain.kicad_sch]
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2024-03-18 Working Debug Menu.
    [PDN.kicad_pcb, power.kicad_sch]
2024-04-16 most recent version pcb and code.
    [PDN.kicad_pcb, PDN.kicad_sch, PDN.step]
2024-04-16 update userID's eeprom usage to avoid losing sense of state
    [main.cpp]
2024-04-16 Switch back to hunter code, clean up serial code.
2024-04-19 added a timeout to checkin and swapped serial order
    [main.cpp]
2024-04-20 bugfixes and debug strings
    [main.cpp]
2024-04-20 find the comms bug
    [main.cpp]
2024-04-20 Remove extra win case from merge with main.
2024-04-21 Swap tx to middle band of trs jack.
    [main.cpp]
2024-04-21 Progress on lights, fixed a bug in bounty activation.
    [main.cpp]
2024-04-22 Corrected match json output.
    [main.cpp]
2024-04-23 Fix enum values for allegiances.
    [main.cpp]
2024-04-23 Move ui refresh to the end of loop, to prevent UI from updating before game state transition.
    [main.cpp]
2024-05-25 Removed PCB from project. All changes from work in the desert on code.
    [PDN.kicad_pcb, PDN.kicad_sch, PDN.step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]
2024-05-31 Change Handshake state to enum
    Switching to enum applies type safety to handshake states to ensure no
    accidental assignments.
2024-05-31 Switch whitespace check to libc
    Use the standard libc isspace instead of custom isWhitespace. This adds
    formfeed ('\f') and vertical tab ('\v') to check which may not be
    desireable, but if it doesn't matter, than this simplifies the code and
    reduces final memory usage by a small amount.
    [main.cpp]
2024-05-31 Begin breaking out comms
    Breaking out communications to separate files reduces the complexity of
    main.cpp, making it easier to read and manage. Eventually, this will
    also allow for more easily swapping between different low level
    communication protocols, such as ESP-NOW or BLE, though more separation
    will be needed first.
    [main.cpp]
2024-06-19 Encapsulate simple timer code
    While the project has the more complex, task based arduino-timer
    library, we often just need a very simple check of duration. main.cpp
    already had a collection of global variables and functions to handle
    this use case. This commit moves those into a simple class to protect
    the variables and also allow for easily having multiple simple timers
    in the future.
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2024-10-09 Device Encapsulation & State Machine (#23)
    * Eve & Elli chaos.
    * Improving device class.
    * I guess I should commit this mess just in case.
    * Flesh out State Machine further.
    * more state machine work.
    * Add StateWithStateMachine to allow for ssub-state-machine processes.
    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
2024-10-09 Unit Testing! (#27)
    * Working tests with mocked device class.
    * Added more State machine Tests
    * Added several more tests.
    * Added state tests.
    * Move project out of pdn-code directory and add test-runner.
    * Add test runner.
2024-10-15 add step to build esp32-s3 image on pr. (#29)
    * add step to build esp32-s3 image on pr.
    * remove source filter from esp32 env.
2024-10-16 Device API's (#30)
    * Add display api to device.
    * refactoring haptics, button and display.
    * wip
    * a lot of device stuff.
2024-11-18 Bug fixes all over the place. (#34)
    [main.cpp, quickdraw-states.hpp]
2024-11-25 Core Game Loop Working on new Architecture. (#35)
    * Fix Player match and opponent id strings being initialized incorrectly.
    * Working Quickdraw duels.
    [quickdraw-states.hpp]
2024-12-20 Add basic P2P wireless capabilities and a remote player discovery (#36)
    * Copy files from initial-esp-now branch
    * Finish esp integration with newer main branch
    This branch replaces the old initial-esp-now branch and this commit
    completes what should be the last of the needed integration. This builds
    but is not at all tested yet.
    * Switch over to using ESP_LOG for logging
    This does not require CDC on boot and also adds extra file information
    to messages, plus adds tagging and log levels, so is all around a
    better solution. You can now see remote player discovery messages
    when using Upload and Monitor command in VSCode.
    ---------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
    [main.cpp]
2025-02-26 Server fuckery (#37)
    * Add MatchManager and refactor match class.
    * Match manager correctly serializes and deserializes match arrays.
    * Fix UUID length issues.
    * clean up warns and main.cpp
    * Add wifi client to device.
    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
    [main.cpp]
2025-03-03 LED Animation Framework - Includes IAnimation Interface & LightManager classes. (#39)
    * fucking with lights
    * lighting algorithms
    * encapsulated light manager
    * create animation interface.
    * Add countdown animation.
    * Add animations.
    * fucking with lights.
    * Working Animation Library with Idle Animation
    * chase led variations.
    * Update hunter idle animation.
    * fix tests.
    [quickdraw-resources.hpp, quickdraw-states.hpp]
2025-03-03 Bounty Idle Animation and more work on animation framework. (#40)
    * New cool idle animation
    * make bounty idle colors better.
    * Separate bounty idle into it's own animation.
    * Added Hunter idle state.
    * Final touches.
2025-03-19 Working wireless (#42)
    * Observer-serial pattern.
    * stuff
    * Handshake over Wireless, debugging serial mac sending.
    * Handshake over Wireless, debugging serial mac sending.
    * Fixed serial, wrote wireless handshake.
    * Bug in bounty handshake
    * Get rid of empty initial file.
    * in the middle of handshake refactor.
    * refactoring handshake
    * fix compile errors.
    * Fix test and compilation errors.
    [main.cpp, quickdraw-states.hpp]
2025-04-04 User Registration Flow w/ Offline Config. (#44)
    * Add loading state!
    * Fetching Player from server
    * True async network calls
    * User Registration Flow with offline config.
2025-04-12 Duel Time (#47)
    * Progress on duel.
    * Duel logic complete but untested.
    * duels working correctly.
    * Moved preferences initialization to later in the event stack. The match manager's constructor was trying to open prefs before the underlying arduino architecture had completed setup.
    * Working match upload after duels, with force match upload function.
    * Add loading ui to upload match state.
    * Clean up some bugs in duel.
    [main.cpp, quickdraw-states.hpp]
2025-04-16 Final 2025 Polish - Lighting Animations, updated draw image, and button masher penalty (#48)
    * Implemented Countdown animation in countdown state.
    * add new lighting states, implemented button masher penalty and prevent repeated play.
    * Further touches.
    [quickdraw-resources.hpp, quickdraw-states.hpp]
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2025-11-01 Build env cleanup (#50)
    * Initial platformio.ini cleanup
    Add a common environment that is shared among all other environments and
    create 3 separate embedded environments:
    1) A release environment that builds with optimizations on and
    minimizes UART serial logging[pdn_release]
    2) A release environment that builds with optimizations on
    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
2026-01-30 Arduino Type Extraction | Driver Framework | Unit Testing
    * Project Clean-Up and Type Extraction
    - cleaned up Readme.md
    - Replaced all instances of arduino String with std::string
    - Addressed ArduinoJson Warnings
    - updated a number of ints to uint_8t.
    - refactored lighting driver.
    * Extract Arduino headers from UUID generator.
    * Refactor SimpleTimer to use a PlatformClock.
    * Created PeerCommsInterface and implemented in ESP-Now-Comms.
    * Created PeerCommsInterface and implemented in ESP-Now-Comms.
    * Refactor Wireless Management, removed wireless manager and created http-client-interface.
    * Fix NPE in simple-timer and move to header implementation.
    * Created logging interface to hide es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
    [main.cpp]
2026-02-02 Driver Update Bug Fixes (#61)
    * progress fixing esp-now/http switching.
    * Fixed wireless state management to restore switching between esp-now and wifi on the esp32.
    * Update logger to output better logs.
    [main.cpp, quickdraw-states.hpp]
2026-02-03 Sonar qube fixes (#60)
    * Sonarqube MCP server setup and fixes.
    * More sonasonar qube fixes
    * Sonar qube analysis issues.
    * Fix compilation errors.
    * Fix test errors after rebase.
    * more fixes.
    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
2026-02-06 PDN CLI Tool (#62)
    * V1 of cli tool.
    * Create multi-device simulator, add http client and add commands.
    * Fix serial driver clearing data before the serial broker could transfer between devices.
    * CLI tool simulates full duels.
    * Add Readme for CLI.
    * Update tests, add test for cli build target.
    [cli-renderer.hpp]
2026-02-06 Move Wifi Credentials to ini file. (#64)
    * Add ini file for wifi configuration.
    * Update character escaping in platformio.ini file
    * Fix github actions to support new wifi-credentials.ini workflow
    [main.cpp]
2026-02-09 Add display mirror with braille rendering, captions, and display commands (#67)
    Overhaul the CLI simulator's display system:
    Driver layer:
    - Proper XBM bitmap decoding via decodeXBMToBuffer (mirrors U8g2)
    - Text glyph backgrounds cleared for visibility over images
    - New renderToBraille() method using Unicode braille (U+2800-U+28FF)
    for 4x detail vs half-blocks, same 64x16 terminal footprint
    Renderer:
    - Terminal height bounds checking prevents scroll corruption
    - Display mirror toggle with braille art rendering
    - Hybrid layout: captions shown alongside first 4 mirror lines
    - Captions toggle (default ON) gates caption visibility
    Commands (moved into CommandProcessor with Renderer& paramet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
    [cli-renderer.hpp]
2026-02-09 Pin the arduinojson version and remove unnecessary build target. (#71)
2026-02-12 Implement state machine management to allow for multiple game experiences (#81)
    * Implement state machine management to allow for multiple game experiences.
    * Fix bugs and add tests.
    * Fix missing serial flush, log statements.
    [main.cpp]
2026-02-15 Break out player registration and handshake from quickdraw. (#90)
    * Break out player registration and handshake from quickdraw.
    * Fix cli tests.
    [main.cpp, quickdraw-resources.hpp, quickdraw-states.hpp]
2026-02-18 Serial Module Implementation (#94)
    * add workspace files to .gitignore
    * SerialManager class implementation
    * add tests to mock device
    * tests
    * routing through SerialManager
    * repairing tests
    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
2026-03-07 Remote Device Coordinator - Enhanced Device Connectivity API for interacting with other devices. (#98)
    * Create RemoteDeviceCoordinator and refactor concepts of handshake.
    Flesh out the RemoteDeviceCoordinator header file.
    Implement RemoteDeviceCoordinator in Quickdraw.
    New Handshakes for RemoteDeviceCoordinator.
    Restructured how handshakes work.
    Add comments to remotedeviceoordinator header.
    * Update to use uint8_t for mac in remote device coordinator.
    * RemoteDeviceCoordinator code for returning one peer
    * build error for HandshakeApp
    * handle null handshake apps
    * cpp17 compatible functions
    * todo stragglers
    * duel state transition to idle fix
    * added serial port ide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
    [main.cpp]
2026-03-27 Update RDC to support multiple device types. (#103)
2026-04-19 RDC chain duel with posse display and loop detection (#110)
    * Chain-duel: daisy-chain topology with supporter boost
    Extends the two-device duel to N-device chains where downstream same-role
    devices act as "supporters" for the champion at the chain head. Supporters
    press their button during COUNTDOWN to send a confirm; each confirm grants
    the champion a 15ms boost on their reaction window.
    ## Transport
    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
2026-04-22 Create a thread safe drain queue for processing incoming ESP-NOW packets. (#112)
    * Create a thread safe drain queue for processing incoming esp-now packets.
    * Update native cli tests.
    * Add similar locks around the send queue.
2026-04-23 Symbol match code for PDN (#114)
    * symbol generation and stats page
    * simple state machine: selection and timer
    * refactoring + introduction of symbol class
    * symbol match connection states
    * symbol manager implementation and connection states
    * symbol match selection flow mostly complete
    * five symbols
    * import errors
    * symbol generation and stats page
    * refactoring + introduction of symbol class
    * symbol manager implementation and connection states
    Made-with: Cursor
    * symbol match selection flow mostly complete
    * pdn symbol match state machine enhancements
    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
    [main.cpp, quickdraw-resources.hpp, quickdraw-states.hpp]
2026-04-24 Shootout tournament mode with RDC loop coordination (#113)
    * Shootout tournament mode with RDC loop coordination
    * Harden shootout: packet validation, disconnect wiring, debounce
    * Shootout hardening + merge upstream main
    * Idle: skip chain-duel init while a shootout is active
    Idle::onStateLoop was calling matchManager->initializeMatch() (chain-duel
    path) while a shootout was underway, overwriting the SHT- match state on
    a bounty device mid-match-1 and stalling the tournament.
    * Shootout: restore original isHunter at each match boundary
    originalIsHunter_ was only restored inside resetToIdle, which doesn't fire
    until a terminal state dismounts (FinalStandings/Aborted). If the ring
    staye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
    [quickdraw-states.hpp]
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2026-06-09 Architecture Migration for Multi-Device Repository (#121)
    * Refactor to prepare for multi-device mono-repo.
    * Create core libraries and separate pdn specific code from core libs.
    * Renormalize line endings to prevent my windows sins to bother everyone else.
    * Remove random readme from include directory.
    * Restore animations. Create utils/easing_curves to remove dependency on quickdraw-resources.
    * Codebase ready for FDN integration.
    * Some small compile issues.
    * Migrate cli code.
    * Convert quickdraw and player registration to TypedStateMachine.
    * Convert ConnectState to always be a device-typed state.
    * Remove AnimationConfig::type and associated cruft code.
    * Remove snapshot cru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
    [cli-renderer.hpp]
2026-06-15 FDN Monorepo Migration (#142)
    * cursor fdn migration
    * restart symnol match game when transitioning back
    * comment unnecessary code
    * broken tests
    [display-utils.hpp, fdn-constants.hpp]
2026-08-03 Crash Log Reporting - With some extras on the side (#221)
    * Add crashlogging with reporting over serial, esp-now or http.
    * Remove forced abort.
    * Allow csv's to be committed so that partitions.csv is part of the codebase.
    * Update json key names for crash logs
    * Add commit hash to commit logs.
    * Remove forced abort again, set up storage driver to throw an exception if invalid namespace is used.
    [partitions.csv]
2026-08-25 Match asan (#260)
    * bound id copies by source; unblock sanitizer suites
    * collapse copyId onto strncpy; guard the setter path
    * surface sanitizer reports in CI; restore capacity guard
    * bound copies by destination; correct sanitizer run notes
    * bound generated match id copy by destination
    * default Match(); document sanitizer gates in README
    * correct sanitizer notes; drop redundant match id copy
    * bound deserialize by destination; revive uuid tests
2026-10-04 Style tooling (#282)
    * Track style config and pre-commit hook
    * Harden style checker against git config and nesting
    * Collapse the no-translation-unit notice to one line
2026-10-14 Idf (#284)
    * build: configure one env on the component path
    (cherry picked from commit dc9d71066ddcc95adebe9b7d6367260401dfb6e2)
    * build: select sources and includes under cmake
    (cherry picked from commit 98c080317285737ea361db586efadb613174624c)
    * drivers: clock, haptics and prefs off arduino
    (cherry picked from commit c5b0d4c535268c0a196d9f52cf637d814acf4d64)
    * drivers: serial jacks on the idf uart driver
    (cherry picked from commit 564ac2bb1c1eb8eaa483aa380abcba5c001dbad9)
    * style: doxygen blocks on the serial driver
    * drivers: esp-now radio and crash log off arduino
    (cherry picked from commit 26714186fb2bd6e965c7bf6c8f5d0390cb678ea8)
    * drivers: wifi station and http off arduino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
2026-10-15 Replace PioArduino w/ Platformio/espressif32 Framework (#289)
    * Collapse State's untyped lifecycle into TypedState<Device>
    * Fix defects IDF's -Wall -Werror reports
    * Build on official espressif32 6.13.0
    * flash_multi: use spellings esptool 4 and 5 accept
    * Make State's lifecycle bridge pure and private again
    * multi_flash: run the platform's esptool.py, not an import
    * Size boostLine for any %lu; correct three comments
    * Correct the StateLifecycle comment on abstract State
    * CI: also build the FDN release and PDN debug envs
    * Updated readme guidance on ide extensions.
    * CI: drop the comment the platform change falsified
2026-10-15 Https Driver adapted for IDF (#291)
    * Verify server certificates and pump async HTTPS transfers
    * HttpRequest carries its own content type
    * One outcome per HTTP attempt, decided from perform()
    * HTTP errors are final: drop willRetry, end attempts cut by disconnect
    * Disconnect fails every queued HTTP request, not just in-flight
    * Native HTTP driver drains its queue on disconnect too
    ---------
2026-10-16 Alleycat-Server & Protobuf Implementation for Device Crash Logs to Alleycat-RS (#292)
    * wip on protobuf, discovered issue with ini file running off to fix.
    * Bring in protobuf types and codegen.
    * Implement protobuf, alleycat-server lib and working crash logs.
    * Move all api calls to alleycat-server.
    * Protobuff build fixes (#293)
    * Build protobuff on main: IDF crash logger, no willRetry
    * Remove a committed build log and local core_dir config
    * Let the HTTP driver bring WiFi up for crash uploads
    * small readme cleanup
    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
2026-10-19 Crash capture fixes (#294)
    * Crash records carry core dump details only when usable
    * Skip the serial poll when USB driver install fails
    * Task watchdog crash records leave out the exception cause
2026-10-19 ESP-NOW firmware distribution (#281)
    * esp-now: widen the packet header to v2 frames
    * esp-now: one frame per send, delete clustering
    * partitions: two application slots, drop unused spiffs
    * comms: per-type send-status handler
    * comms: style fixes for send-status handler
    * firmware: wire format for distribution frames
    * firmware: restore include order
    * style: apply project clang-format across the branch
    * firmware: store interface and native fake
    * firmware: read back the written slot
    * firmware: verify the root-signed delegation chain
    * firmware: fix native envs, pin the chain's anchor
    * firmware: receiver collects chunks into the inactive slot
    * firmware: bound chunk writes,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
2026-10-19 esp32-drivers: sync system clock from HTTP Date response header (#297) (#300)
    * esp32-drivers: sync system clock from HTTP Date response header (#297)
    * openspec: add http-date-clock-sync spec
2026-10-24 Alleycat-Server Types Refactor (#303)
    * Refine the data types coming from alleycat-rs to not be so memory intensive.
    * Added UUIDBytes class to further reduce memory pressure of api objects.
    * use memcpy instead of idgenerator copyid method.
    * Update to match backend spec.
2026-10-26 Alleycat RS Integration w/ New PlayerFetchApp and PlayerProvider (#302)
    * create new PlayerFetch App to work with rust server data types.
    * Update spec
    * Implement PlayerProvider and PlayerV2, removed intermediate DevicePlayer layer.
    * line counter for pr's.
    * Player-By-Pin successfully fetching players in player-fetch app.
    * Remove Playerv2, instead add fields to old player object and create shim layer to render old player types until full cutover.
    * Remove player-registration app and replace with player-fetch.
    * Self Review Cleanup.
    * Fix tests.
    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
2026-10-28 Handshake wireless manager did not send device type on outgoing message.
